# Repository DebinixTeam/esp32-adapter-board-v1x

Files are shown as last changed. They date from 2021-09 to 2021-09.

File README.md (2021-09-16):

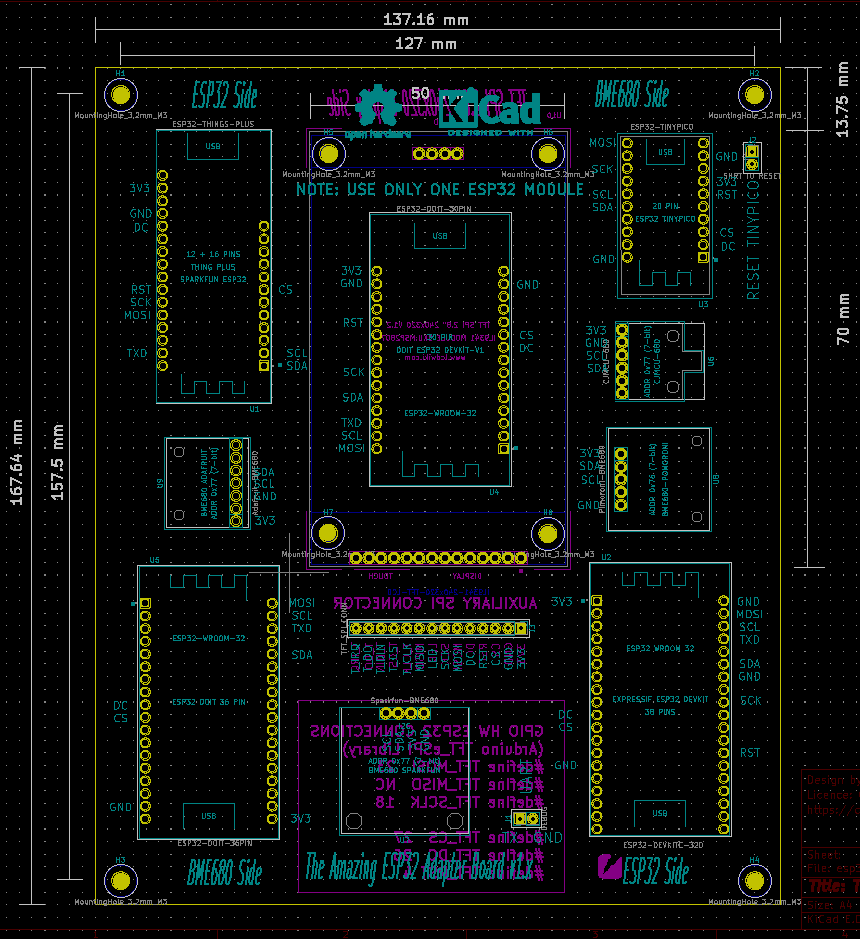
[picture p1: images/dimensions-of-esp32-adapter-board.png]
prototyping solderable board


# The Amazing ESP32 Adapter Board v1.x

## Use cases 
 
 * This adapter board was used to create a [nautical precision barometer](https://github.com/DebinixTeam/esp32-nautical-barometer-gold) with a unique pressure history function. This [instructable](https://www.instructables.com/Your-Nautical-Barometer-Gold-for-Precise-Weather-F/) documents the project. Find the tested ESP32 modules and pressure sensor in the nautical barometer project [here](https://github.com/DebinixTeam/esp32-nautical-barometer-gold/blob/master/hw-compatibility-list.md).

* The adapter board has numerous I2C header positions for various pressure sensors. However, any I2C breakout board can be used with DuPont wires to match individual signals.

* Almost every ESP32 DIY project requires a TFT SPI display, and this is already built-in. Just plug-and-play. 

* Use the auxiliary connector to test touch panel functionality if the display supports it.

* Use the UART TX port for code debugging.

* Test various ESP32 modules, easy to swap out before deciding which one to put into an actual product.

* The routed GPIO are the ones required for SPI and I2C buses. Thus, it eliminates the breadboard DuPont wire bus rats net!

* Solder `female headers` to the ESP development module, and you have access to all other signals via DuPont wires to a breadboard.

## Specification for The Amazing ESP32 Adapter Board v1.x

This adapter board is fabricated as two layer board with the dimensions 5.4"x6.6" (137.16 x 167.64 mm).

| parameter | imperial | metric |
| ---|---|---|
| board material | FR4 | FR4 |
| board thickness | 63 mil | 1.6 mm |
| M3 mounting holes | 1/8" | 3.2 mm |
| header hole diameter | 39.4 mil | 1.0 mm |
| surface finish | HASL (with lead) | HASL (with lead) |
| copper layer thickness | 1.4 mil | 35 um |
| board color | green | green |
| board text | white | white |
| board weight | 2.82 oz | 80 gram |

## Fabrication of the board by yourself

This project is open-source, so that you will find KiCad PCB board design files and gerbers in this repository. Therefore, feel free to modify these files to fit your specific need.

You can directly upload files in the `fabrication/gerbers` folder to PCB prototype services like [OSHPark](https://oshpark.com), [EUROcircuits](https://www.eurocircuits.com/), [JLCPCB](https://jlcpcb.com/), or [PCBWay](https://www.pcbway.com/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). Fabrication costs for small quantities vary considerably among suppliers.

## 2.8" 240x320 TFT SPI Display

The board is designed for this particular [2.8" TFT SPI Display](http://www.lcdwiki.com/2.8inch_SPI_Module_ILI9341_SKU:MSP2807). This display can be found on line from various sources, by searching for `SKU:MSP2807`.

## I2C breakout boards

The adapter board uses I2C for various pressure sensors. However, it can still be used for other I2C based breakout boards, either directly if the pin order is identical or using DuPont wires to match individual signals as shown in the [schematic](./kicad/esp32-adapter-schematic-v1x.pdf).

## Female headers

You have the choice to use [female headers](https://www.amazon.com/Glarks-Straight-Connector-Assortment-Prototype/dp/B076GZXW3Z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) or permanently `solder` the parts to the board.

## Other sources of the adapter board
You can also purchase the latest designed boards on `Tindie`. 

Tindie (https://www.tindie.com/products/debinix/common-esp32s-on-one-adapter-board/)

I appreciate your support.

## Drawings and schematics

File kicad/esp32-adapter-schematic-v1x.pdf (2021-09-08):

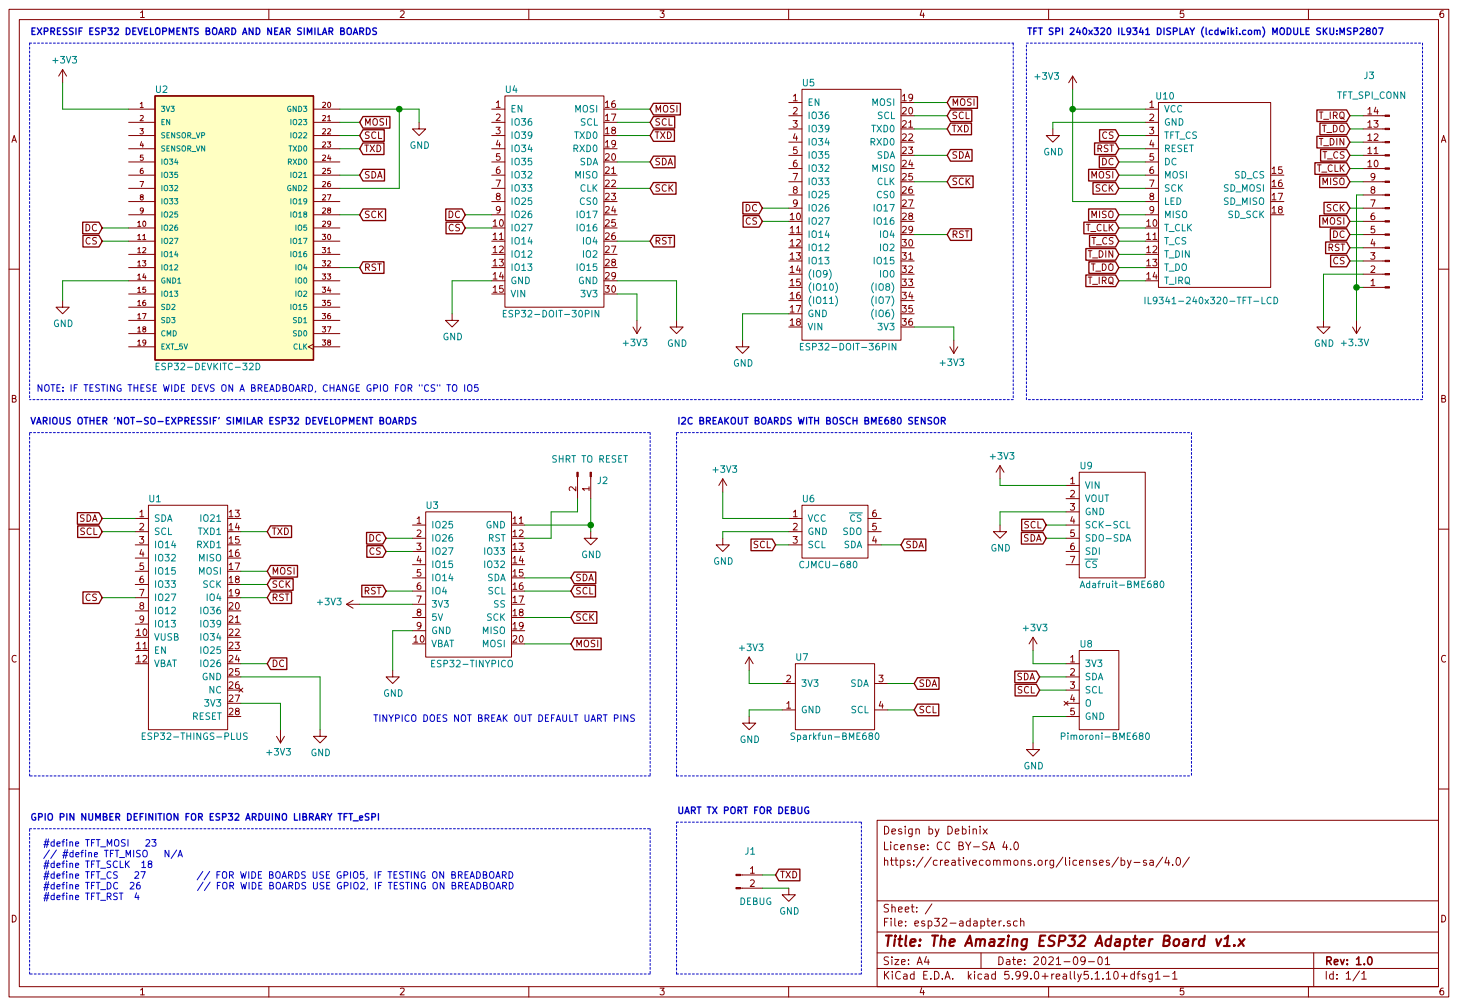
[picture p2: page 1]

J2 SHRT TO RESET EN 1
TXD

EXPRESSIF ESP32 DEVELOPMENTS BOARD AND NEAR SIMILAR BOARDS

SCK UART TX PORT FOR DEBUG GPIO PIN NUMBER DEFINITION FOR ESP32 ARDUINO LIBRARY TFT_eSPI NOTE: IF TESTING THESE WIDE DEVS ON A BREADBOARD, CHANGE GPIO FOR "CS" TO IO5 VARIOUS OTHER 'NOT-SO-EXPRESSIF' SIMILAR ESP32 DEVELOPMENT BOARDS

I2C BREAKOUT BOARDS WITH BOSCH BME680 SENSOR

TINYPICO DOES NOT BREAK OUT DEFAULT UART PINS

File: esp32-adapter.sch Sheet: / https://creativecommons.org/licenses/by-sa/4.0/ License: CC BY-SA 4.0 Design by Debinix

Id: 1/1 Title: The Amazing ESP32 Adapter Board v1.x

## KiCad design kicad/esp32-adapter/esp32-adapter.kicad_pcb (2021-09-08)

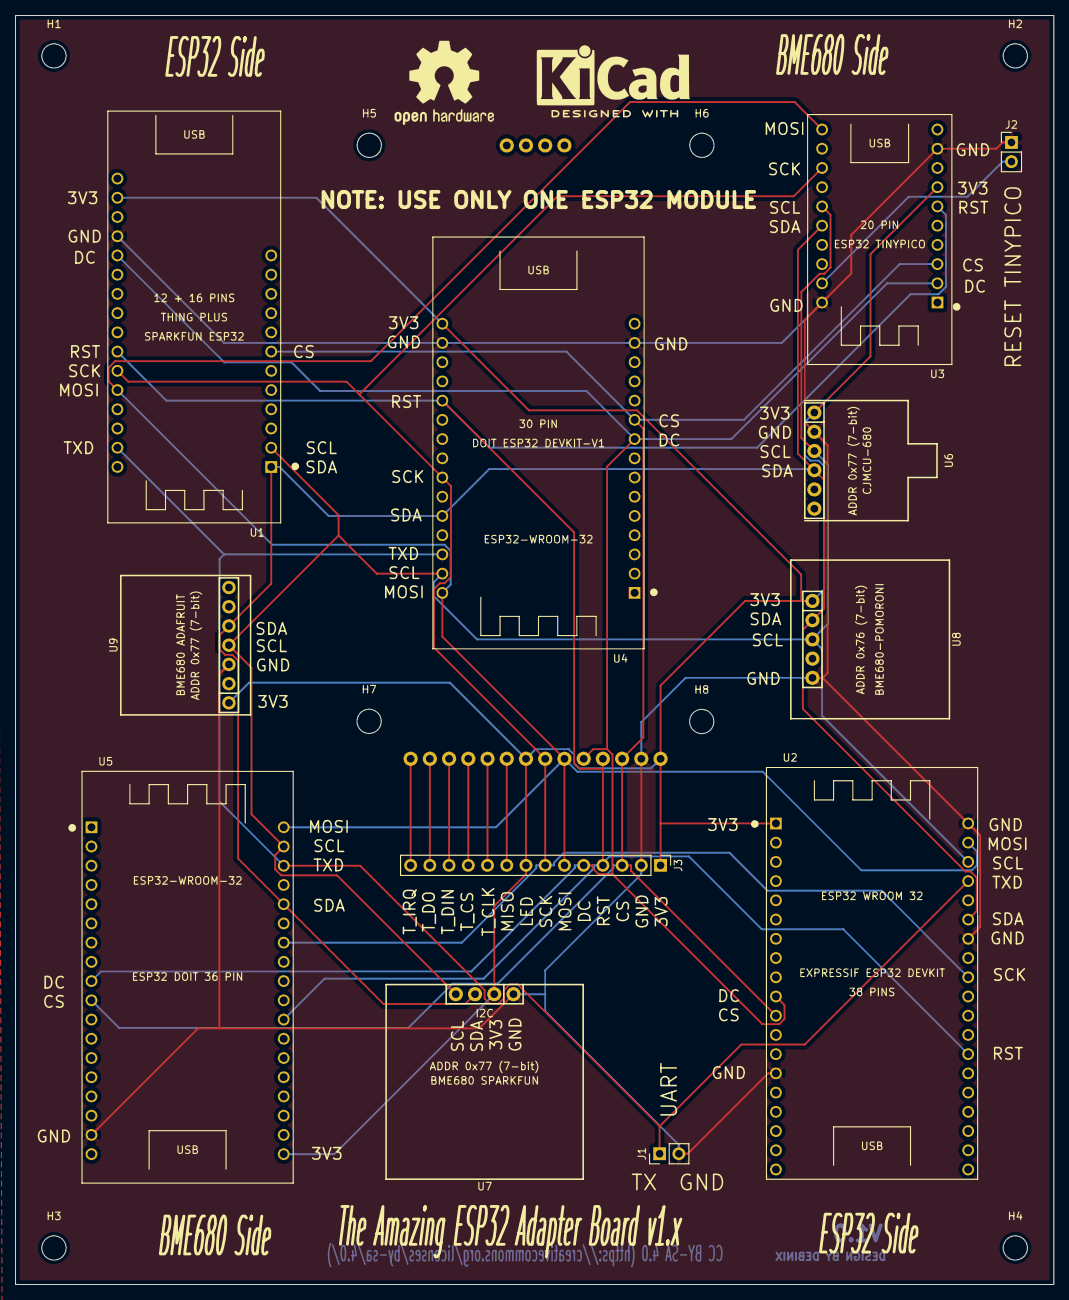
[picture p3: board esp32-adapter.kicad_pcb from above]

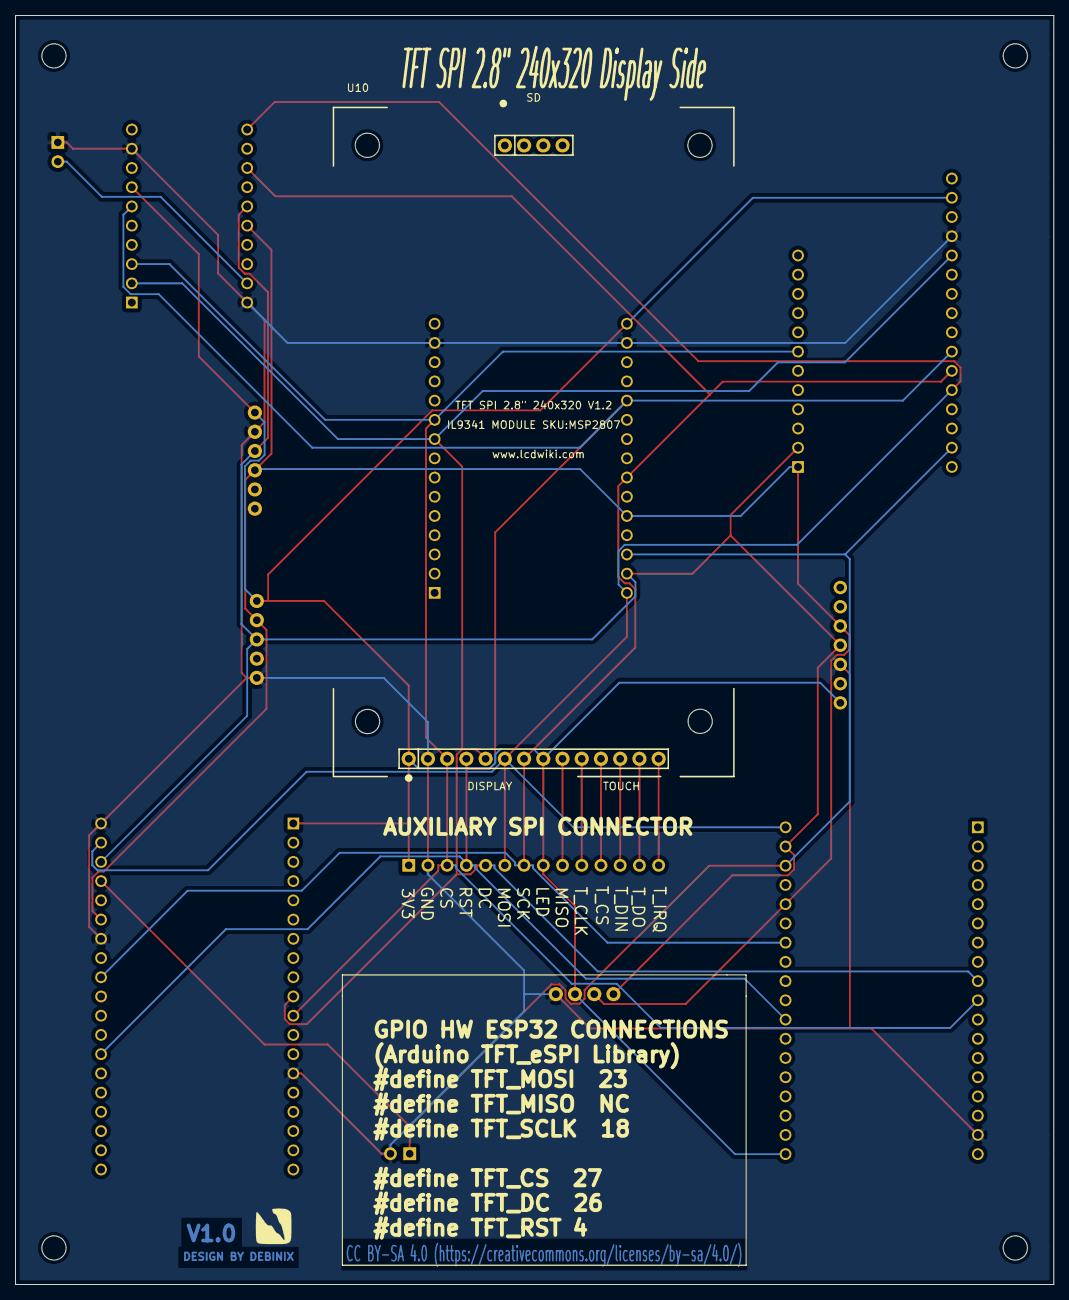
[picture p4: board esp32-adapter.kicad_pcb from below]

Board: 2 copper layers, 137.2 x 167.6 mm, 24 parts (2 on the bottom side), 17 nets.

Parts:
G1: LOGO; flash
G2: OSHW-Logo2_14.6x12mm_SilkScreen
G3: KiCad-Logo2_8mm_SilkScreen
H1, H2, H3, H4, H5, H6, H7, H8: MountingHole_3.2mm_M3
J1: DEBUG; PinHeader_1x02_P2.54mm_Vertical
J2: SHRT TO RESET; PinHeader_1x02_P2.54mm_Vertical
J3: TFT_SPI_CONN; PinHeader_1x14_P2.54mm_Vertical
U1: ESP32-THINGS-PLUS; SPARKFUN_ESP32-THING-PLUS
U2: ESP32-DEVKITC-32D; MODULE_ESP32-DEVKITC-32D
U3: ESP32-TINYPICO; ESP32_TINY_PICO
U4: ESP32-DOIT-30PIN
U5: ESP32-DOIT-36PIN
U6: CJMCU-680; BME680-CJMCU-680
U7: Sparkfun-BME680; BME680-SPARKFUN
U8: Pimoroni-BME680; BME680-PIMORONI
U9: Adafruit-BME680; BME680-ADAFRUIT
U10: IL9341-240x320-TFT-LCD; IL9341-TFTSPI-240x320V1_2

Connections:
+3V3: J3.1, J3.8, U1.27, U2.1, U3.7, U4.30, U5.36, U6.1, U7.2, U8.1, U9.1, U10.1, U10.8
CS: J3.3, U1.7, U2.11, U3.3, U4.10, U5.10, U10.3
DC: J3.5, U1.24, U2.10, U3.2, U4.9, U5.9, U10.5
GND: J1.2, J2.1, J3.2, U1.25, U2.14, U2.20, U2.26, U3.9, U3.11, U4.14, U4.29, U5.17, U6.2, U7.1, U8.5, U9.3, U10.2
MISO: J3.9, U10.9
MOSI: J3.6, U1.17, U2.21, U3.20, U4.16, U5.19, U10.6
unnamed: J2.2, U3.12
RST: J3.4, U1.19, U2.32, U3.6, U4.26, U5.29, U10.4
SCK: J3.7, U1.18, U2.28, U3.18, U4.22, U5.25, U10.7
SCL: U1.2, U2.22, U3.16, U4.17, U5.20, U6.3, U7.4, U8.3, U9.4
SDA: U1.1, U2.25, U3.15, U4.20, U5.23, U6.4, U7.3, U8.2, U9.5
TXD: J1.1, U1.14, U2.23, U4.18, U5.21
T_CLK: J3.10, U10.10
T_CS: J3.11, U10.11
T_DIN: J3.12, U10.12
T_DO: J3.13, U10.13
T_IRQ: J3.14, U10.14

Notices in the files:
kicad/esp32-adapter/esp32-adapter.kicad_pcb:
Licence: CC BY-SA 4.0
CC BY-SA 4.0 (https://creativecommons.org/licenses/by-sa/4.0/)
